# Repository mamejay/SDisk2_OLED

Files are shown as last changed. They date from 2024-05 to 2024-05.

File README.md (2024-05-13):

***** Updated Version Using SMD Components *****

I have updated the PCB to use all SMD components and tactile switches
I have re-compiled the code and confirmed is working.

# SDisk2 - Simplified

Disk II flopy drive emulator for Apple 2 computers

Objective. an Open Source Disk II floppy Disk emulator that is easy to make.  
See readme in firmware and PCB section for related info.

## Changes

* 27Mhz Xtal.
* OLED only. All LCD and Nokia LCD codes have been removed.
* All Screen rotation code removed.
* Buttons re-arranged

## To-do

1. Better documentaion of the code.

This project will be migrated to an ESP32 based SDISKII.
<https://github.com/terenceang/sdisk2esp>

## Authors

* (c) 2010 Koichi NISHIDA <tulip-house@msf.biglobe.ne.jp>
* (c) 2012 Victor Trucco
* (c) 2012 Fábio Belavenuto
* (c) 2015 Alexandre Suaide
* (c) 2022 Terence Ang

## License

This work is released under the version 3 of the GNU General Public License.

'''NOTE:'''
The current legal status of this code is uncertain.

Fábio and Alexandre have published files with a header that references the version 3 of the GNU General Public License, but it is not clear yet what's the licensing chosen by the original author, Koichi Nishida.

This repository will be updated once the actual licensing info is clarified by the authors.

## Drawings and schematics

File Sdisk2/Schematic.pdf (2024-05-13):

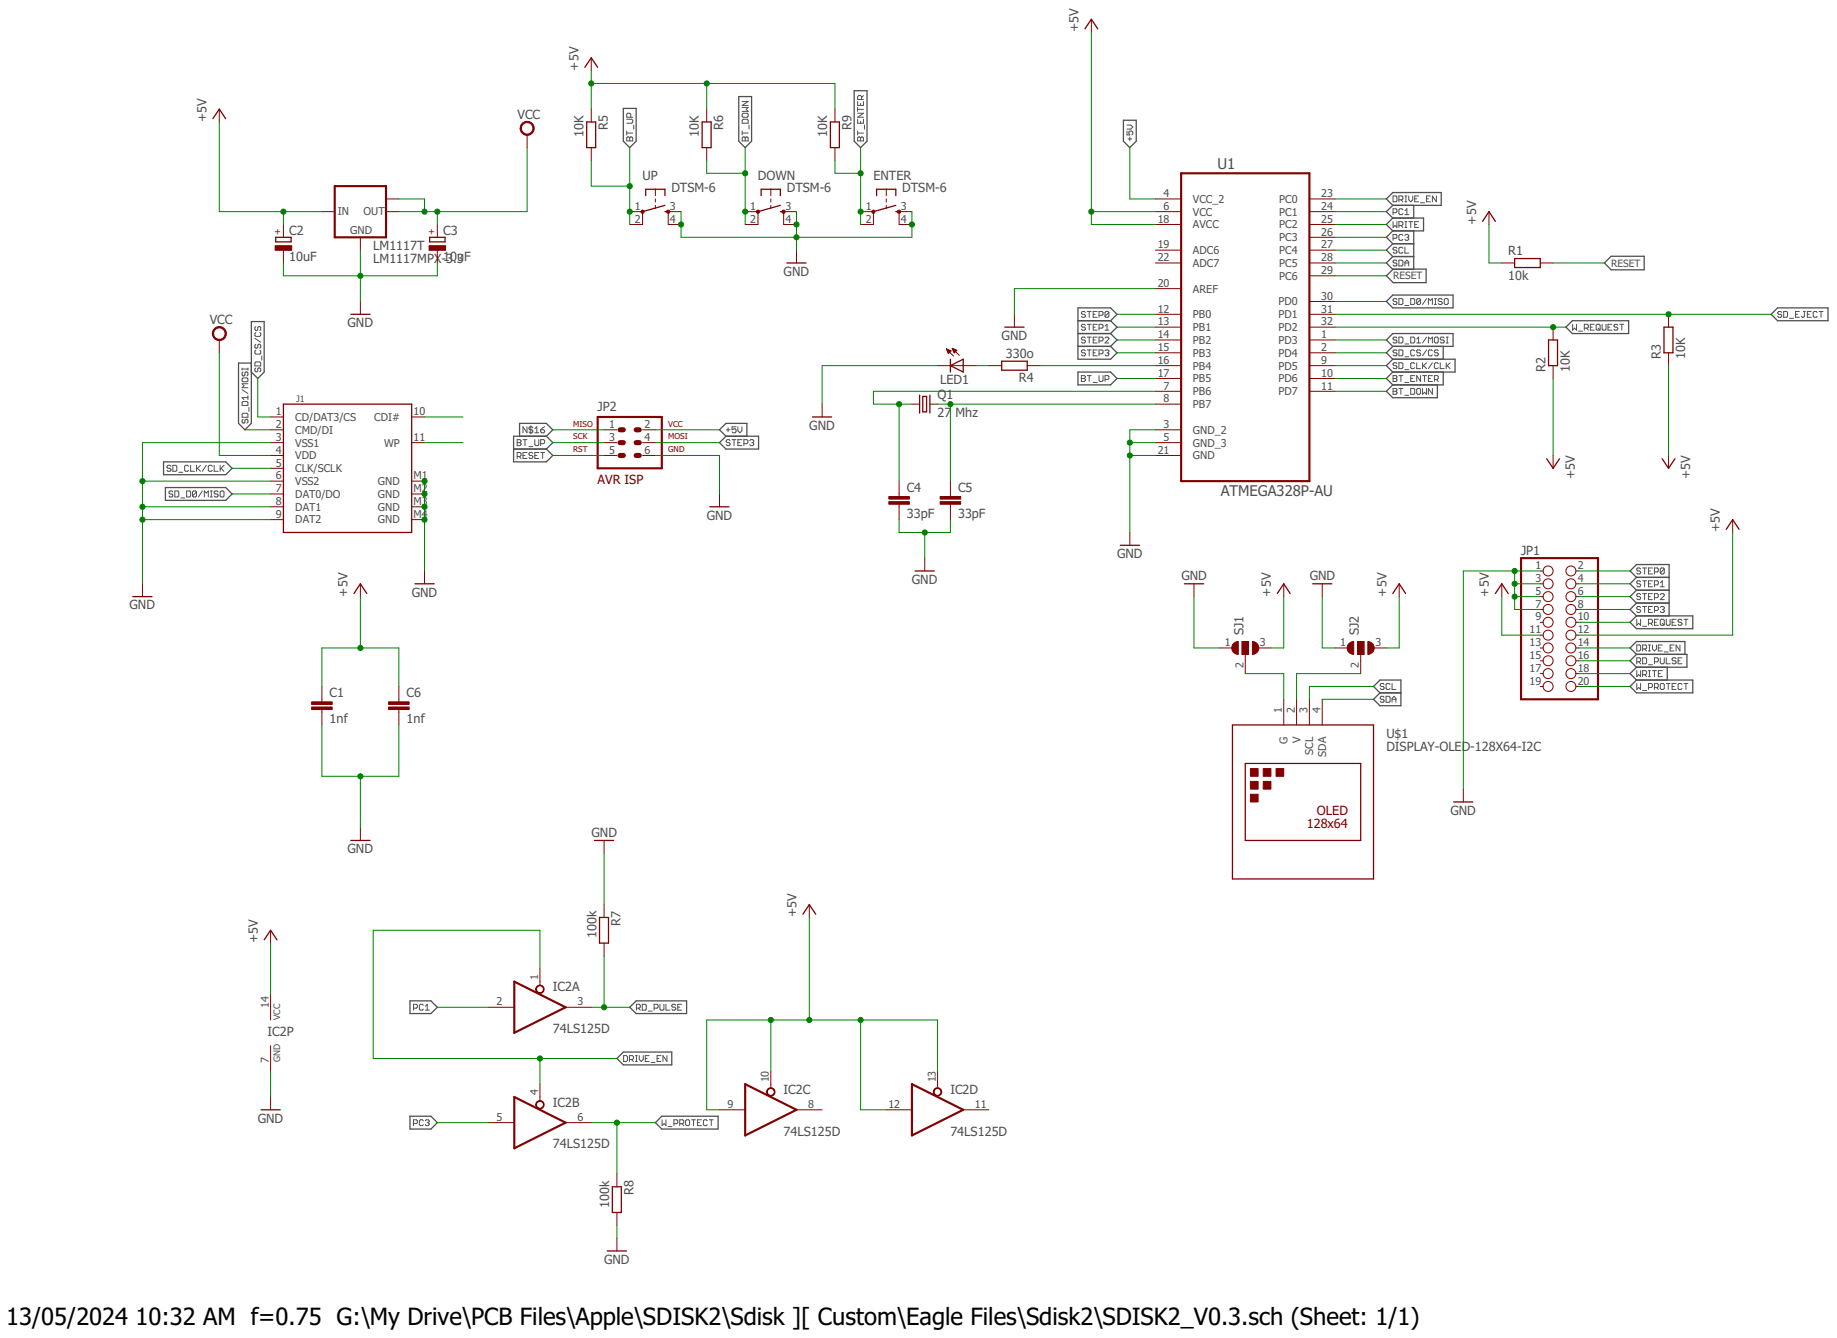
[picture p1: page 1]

13/05/2024 10:32 AM f=0.75 G:\My Drive\PCB Files\Apple\SDISK2\Sdisk ][ Custom\Eagle Files\Sdisk2\SDISK2_V0.3.sch (Sheet: 1/1)

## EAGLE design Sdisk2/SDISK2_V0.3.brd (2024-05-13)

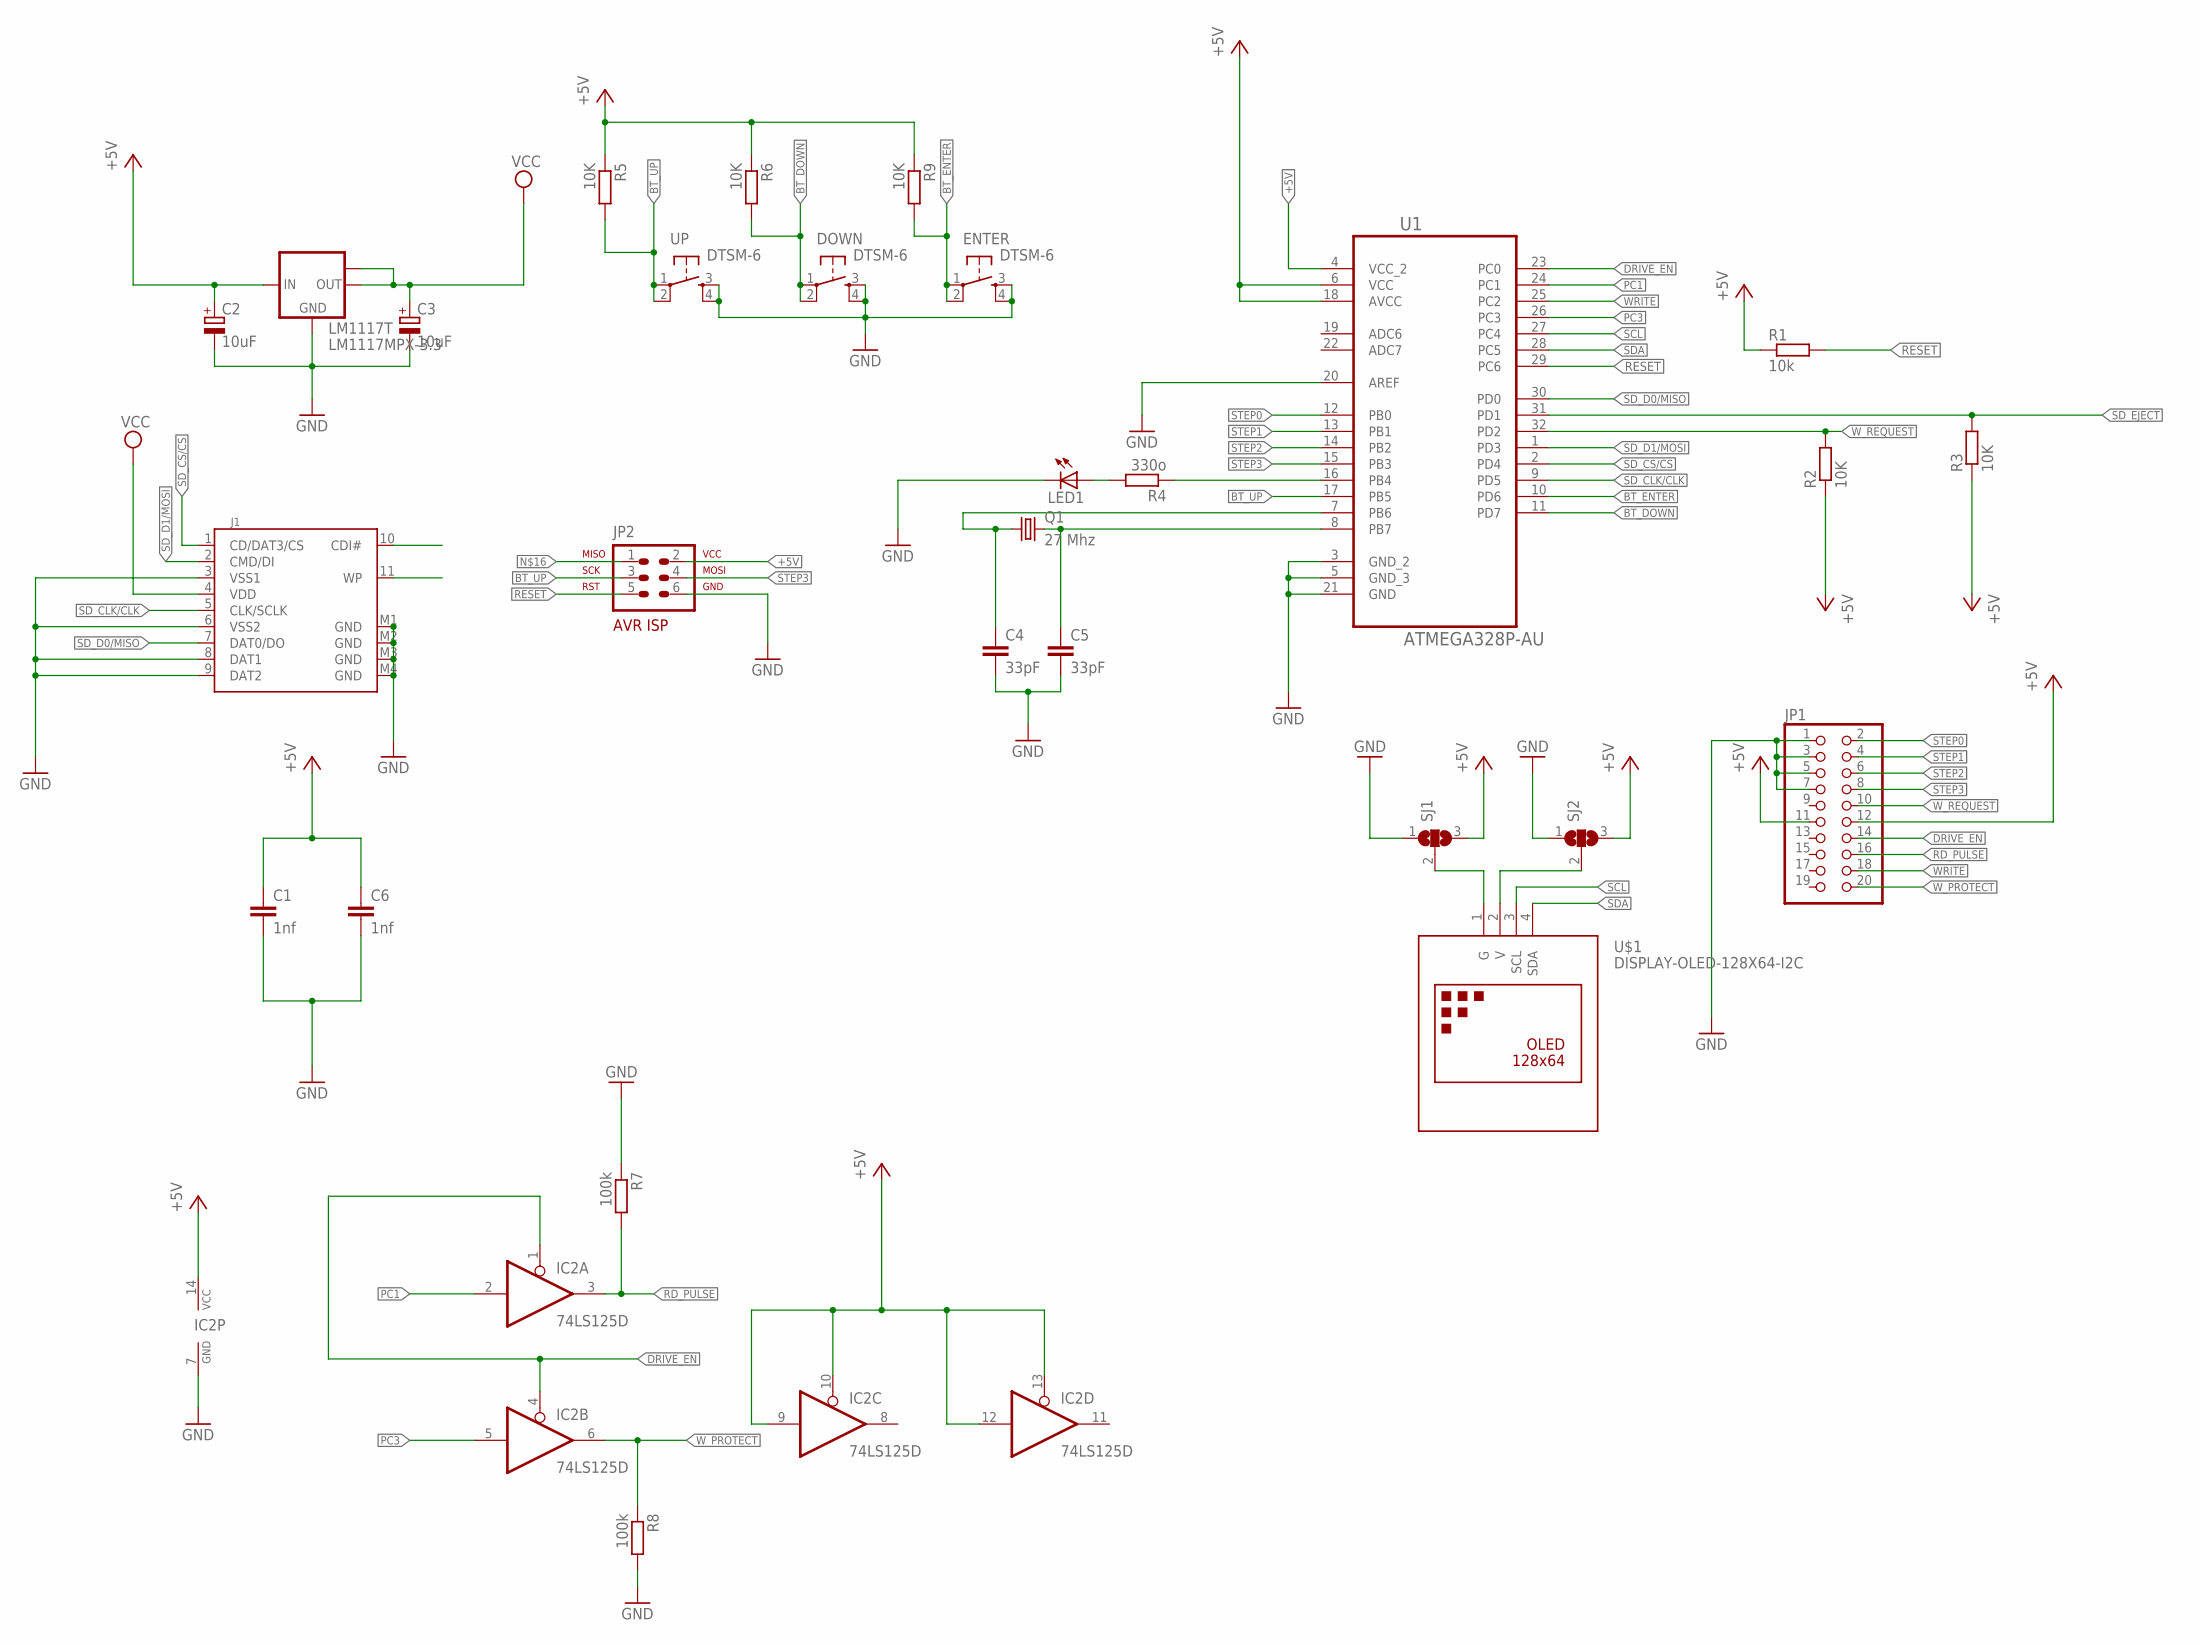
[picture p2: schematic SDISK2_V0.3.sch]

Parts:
C1, C6: 1nf; C0805
C2, C3: 10uF; 153CLV-0405
C4, C5: 33pF; C0805
DOWN: DTSM-6
ENTER: DTSM-6
IC2: 74LS125D; SO14
J1: SDCARD; SDCMF-10915W010
JP1: PINHD-2X10_IDC2X10_IDC_NEW; 2X10_IDC
JP2: AVR-ISP-6VERT; AVR-ISP-6
LED1: LEDSML1206; SML1206
LM1117T: LM1117MPX-3.3; SOT223
Q1: 27 Mhz; HC49UP
R1: 10k; R0805
R2, R3, R5, R6, R9: 10K; R0805
R4: 330o; R0805
R7, R8: 100k; R0805
SJ1, SJ2: SJ2W; SJ_2
U1: ATMEGA328P-AU; QFP80P900X900X120-32N
U$1: DISPLAY-OLED-128X64-I2C
UP: DTSM-6

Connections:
3.3V: C3.+, J1.4 (VDD), LM1117T.2 (OUT), LM1117T.TAB (OUT1)
+5V: C1.1, C2.+, C6.1, IC2.9 (I), IC2.10 (OE), IC2.12 (I), IC2.13 (OE), IC2.14 (VCC), JP1.11, JP1.12, JP2.2, LM1117T.3 (IN), R1.1, R2.1, R3.1, R5.1, R6.1, R9.1, SJ1.3, SJ2.3, U1.4 (VCC_2), U1.6 (VCC), U1.18 (AVCC)
BT_DOWN: DOWN.1, DOWN.2, R6.2, U1.11 (PD7)
BT_ENTER: ENTER.1, ENTER.2, R9.2, U1.10 (PD6)
BT_UP: JP2.3, R5.2, U1.17 (PB5), UP.1, UP.2
DRIVE_EN: IC2.1 (OE), IC2.4 (OE), JP1.14, U1.23 (PC0)
GND: C1.2, C2.-, C3.-, C4.2, C5.2, C6.2, DOWN.3, DOWN.4, ENTER.3, ENTER.4, IC2.7 (GND), J1.3 (VSS1), J1.6 (VSS2), J1.8 (DAT1), J1.9 (DAT2), J1.M1 (GND), J1.M2 (GND), J1.M3 (GND), J1.M4 (GND), JP1.1, JP1.3, JP1.5, JP1.7, JP2.6, LED1.C, LM1117T.1 (GND), R7.1, R8.2, SJ1.1, SJ2.1, U1.3 (GND_2), U1.5 (GND_3), U1.20 (AREF), U1.21 (GND), UP.3, UP.4
unnamed: C4.1, Q1.1, U1.7 (PB6)
unnamed: LED1.A, R4.2
unnamed: SJ1.2, U$1.1 (G)
unnamed: SJ2.2, U$1.2 (V)
unnamed: JP2.1, R4.1, U1.16 (PB4)
unnamed: C5.1, Q1.2, U1.8 (PB7)
PC1: IC2.2 (I), U1.24 (PC1)
PC3: IC2.5 (I), U1.26 (PC3)
RD_PULSE: IC2.3 (O), JP1.16, R7.2
RESET: JP2.5, R1.2, U1.29 (PC6)
SCL: U1.27 (PC4), U$1.3 (SCL)
SDA: U1.28 (PC5), U$1.4 (SDA)
SD_CLK/CLK: J1.5 (CLK/SCLK), U1.9 (PD5)
SD_CS/CS: J1.1 (CD/DAT3/CS), U1.2 (PD4)
SD_D0/MISO: J1.7 (DAT0/DO), U1.30 (PD0)
SD_D1/MOSI: J1.2 (CMD/DI), U1.1 (PD3)
SD_EJECT: R3.2, U1.31 (PD1)
STEP0: JP1.2, U1.12 (PB0)
STEP1: JP1.4, U1.13 (PB1)
STEP2: JP1.6, U1.14 (PB2)
STEP3: JP1.8, JP2.4, U1.15 (PB3)
WRITE: JP1.18, U1.25 (PC2)
W_PROTECT: IC2.6 (O), JP1.20, R8.1
W_REQUEST: JP1.10, R2.2, U1.32 (PD2)

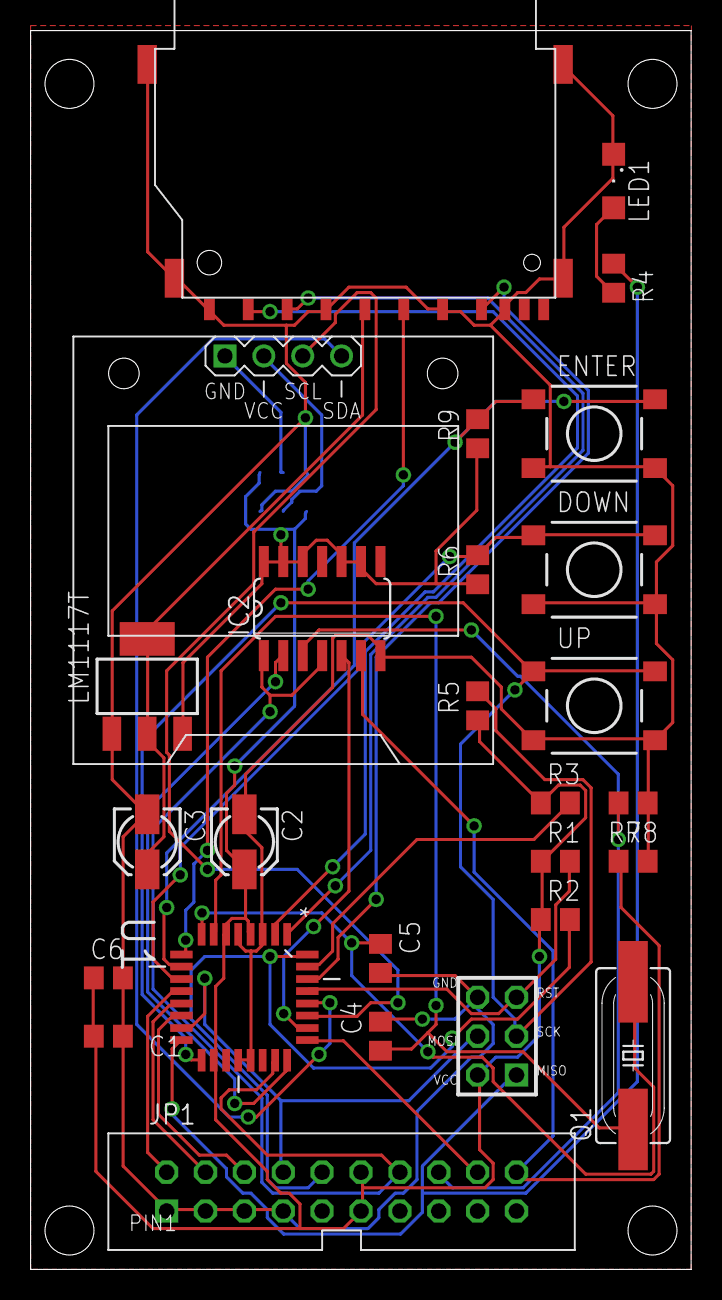
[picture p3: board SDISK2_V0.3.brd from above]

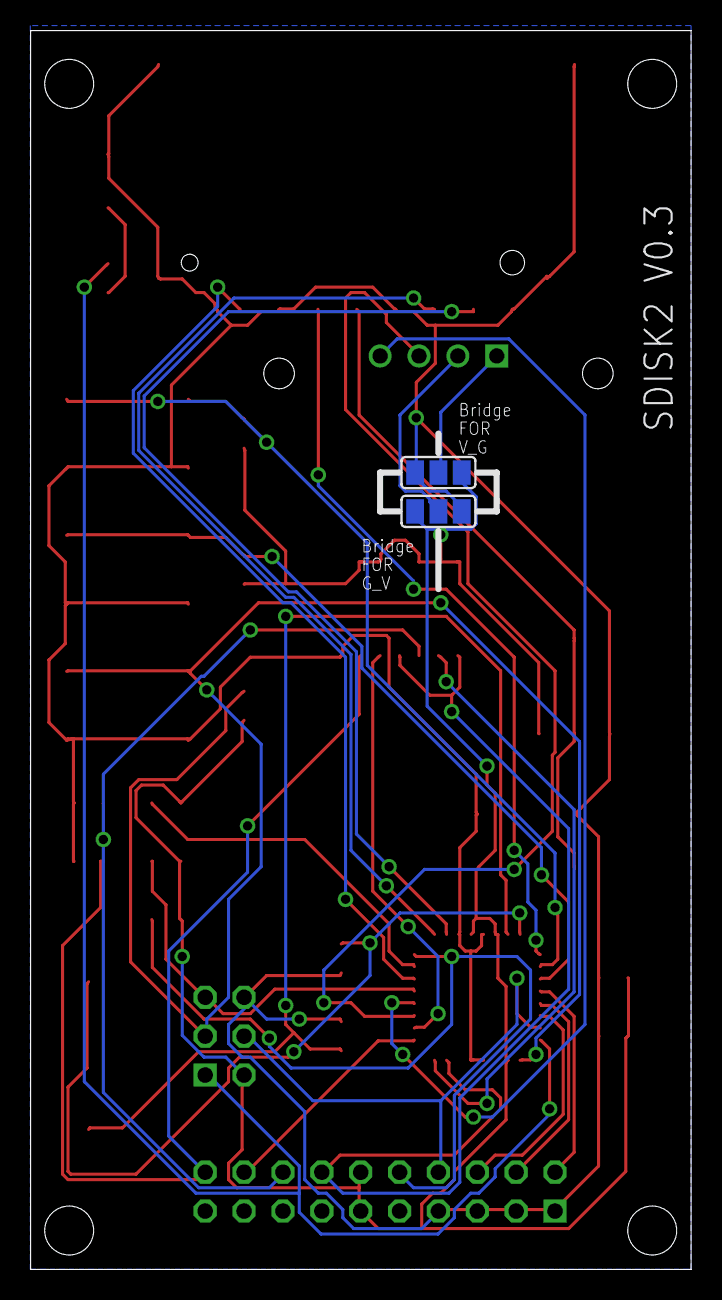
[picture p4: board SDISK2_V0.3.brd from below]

Board: 2 copper layers, 43.2 x 81.0 mm, 29 parts (2 on the bottom side), 31 nets.

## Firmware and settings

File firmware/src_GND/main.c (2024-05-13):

/*------------------------------------
SDISK II LCD Firmware
2010.11.11 by Koichi Nishida
2012.01.26 by Fábio Belavenuto
2015.07.02 by Alexandre Suaide
-------------------------------------
*/

/*
2015.07.02 by Alexandre Suaide
Added support for SDHC cards and subdirectories
Removed DSK to NIC conversion
FAT16 and FAT32 disks should have at least 64 blocks per cluster
*/

/*
2012.01.26 by Fábio Belavenuto
Added support for image exchange using a button added in the Brazilian version by Victor Trucco
Added support for a 16x2 LCD
*/

/*
This is a part of the firmware for DISK II emulator by Nishida Radio.
Copyright (C) 2010 Koichi NISHIDA
email to Koichi NISHIDA: tulip-house@msf.biglobe.ne.jp
This program is free software; you can redistribute it and/or modify it
under the terms of the GNU General Public License as published by
the Free Software Foundation; either version 3 of the License.
This program is distributed in the hope that it will be useful,
but WITHOUT ANY WARRANTY; without even the implied warranty of
MERCHANTABILITY or FITNESS FOR A PARTICULAR PURPOSE.
See the GNU General Public License for more details.
You should have received a copy of the GNU General Public License
along with this program. If not, see <http://www.gnu.org/licenses/>.
*/

#include "main.h"

#define BUF_NUM 4 // originalmente era 5. testando por conta de um possivel overflow de memoria na sdisk nova com oled
unsigned char writeData[BUF_NUM][350];
unsigned char sectors[BUF_NUM], tracks[BUF_NUM];
unsigned char buffNum;
unsigned char *writePtr;
unsigned char flip_buttons;

#define DEBOUNCE 200

#define MAXFILES 200
unsigned char *files_id;
int nfiles = 0;
int selected_file_id = 0;
int id_of_config_file = -1;

#define FAT_NIC_ELEMS 10
#define NIC_FILE_SIZE 280
unsigned long fatNic[FAT_NIC_ELEMS];

// DISK II status
unsigned char ph_track; // 0 - 139
unsigned char sector;	// 0 - 15
unsigned short bitbyte; // 0 - (8*512-1)
unsigned char prepare;
unsigned char readPulse;
unsigned char inited;
unsigned char magState;
unsigned char protect;
unsigned char formatting;
const unsigned char volume = 0xfe;

unsigned char trk;
unsigned short long_sector;
unsigned short long_cluster;
unsigned long ft;
unsigned char old_trk;

/*Error codes
1 - Can not put SD Card on idle state
2 - Can not make SD Card initialization
3 - Can not init FAT
4 - Partition type not supported (only FAT16 and FAT32)
5 - Cluster size smaller than minimum to keep buffer
*/

/*                               012345678901234567890*/
PROGMEM const char SPLASH1[] = "      SDISK ][";
PROGMEM const char VERSION[] = "  version " VER " " YEAR;
PROGMEM const char NIC[] = " NIC                 ";
PROGMEM const char SETUP[] = " SETUP               ";
PROGMEM const char EMP[] = "                     ";
PROGMEM const char SET1[] = " Set SD delay        ";
PROGMEM const char SET2[] = " Set contrast        ";
PROGMEM const char SET3[] = " Rotate display      ";
PROGMEM const char VALUE[] = " Value: ";
PROGMEM const char CONT[] = " LCD CONTRAST        ";
PROGMEM const char DLAY[] = " SD SELECT DELAY     ";
PROGMEM const char TRAK[] = "Track: ";
PROGMEM const char MSG7[] = " SELECT NIC          ";
PROGMEM const char MSGC[] = " Building list";
PROGMEM const char MSG8[] = " Nothing found here! ";
PROGMEM const char MSGD[] = " Sorting files ...   ";
PROGMEM const char MSHC[] = "SDHC card     ";
PROGMEM const char MSSD[] = "Normal SD card";
PROGMEM const char ERR[] = "E R R O R";
PROGMEM const char ERM1[] = "SD can't idle ";
PROGMEM const char ERM2[] = "SD can't init ";
PROGMEM const char ERM3[] = "Boot sector   ";
PROGMEM const char ERM4[] = "Not FAT16/32  ";
PROGMEM const char ERM5[] = "Cluster < 32kB";
PROGMEM const char ERM6[] = "Missing MBR   ";
PROGMEM const char ERM7[] = "SD Block ERROR";
PROGMEM const char ERMC[] = "Code: ";
PROGMEM const char PART[] = "Type: ";
PROGMEM const char FAT3[] = "FAT32";
PROGMEM const char FAT1[] = "FAT16";
PROGMEM const char SDOUT[] = "No SD inserted";
#define TRX 12
#define TRY 4

PROGMEM const char CFG[] = "SDISKII CFG";

// a table for head stepper motor movement
PROGMEM const prog_uchar stepper_table[4] = {0x0f, 0xed, 0x03, 0x21};

int main(void)
{
	static unsigned char oldStp = 0, stp;
	init(1);
	old_trk = 255;
	while (1)
	{
		verify_status();
		if (diskII_disable())
		{
			SD_led_off();
		}
		else
		{
			SD_led_on();
			stp = (PINB & 0b00001111);
			if (stp != oldStp)
			{
				oldStp = stp;
				unsigned char ofs = ((stp == 0b00001000) ? 2 : ((stp == 0b00000100) ? 4 : ((stp == 0b00000010) ? 6 : ((stp == 0b00000001) ? 0 : 0xff))));
				if (ofs != 0xff)
				{
					ofs = ((ofs + ph_track) & 7);
					unsigned char bt = pgm_read_byte_near(stepper_table + (ofs >> 1));
					oldStp = stp;
					if (ofs & 1)
						bt &= 0x0f;
					else
						bt >>= 4;
					ph_track += ((bt & 0x08) ? (0xf8 | bt) : bt);
					if (ph_track > 196)
						ph_track = 0;
					if (ph_track > 139)
						ph_track = 139;
				}
			}

			if (inited && prepare)
			{
				cli();
				sector = ((sector + 1) & 0xf);
				{
					trk = (ph_track >> 2);
					long_sector = (unsigned short)trk * 16 + sector;
					long_cluster = long_sector >> FAT_sectorsPerClusterBitShift;
					ft = fatNic[long_cluster];
					if (trk != old_trk)
					{
						old_trk = trk;
						ssd1306_gotoxy(TRX, TRY);
						ssd1306_put_p(TRAK);
						if (trk < 10)
							ssd1306_string(" ");
						ssd1306_put_i((unsigned int)trk);
					}

					if (((sectors[0] == sector) && (tracks[0] == trk)) || ((sectors[1] == sector) && (tracks[1] == trk)) ||
						((sectors[2] == sector) && (tracks[2] == trk)) || ((sectors[3] == sector) && (tracks[3] == trk)))
						writeBackSub();

					// Timing is an issue here. This is the reason I copied explicitly the conversion from cluster to block
					// instead of using getCluster() method. I also did bit shift instead of multiplications to make it faster.
					// even inline function is not fast enough.
					// SD_CMD17Special is also faster than the regular SD_sendCommand method.
					SD_CMD17Special((((ft - 2) << FAT_sectorsPerClusterBitShift) + FAT_firstDataSector) + (long_sector & (FAT_sectorsPerCluster - 1)));
					bitbyte = 0;
					prepare = 0;
				}

				sei();
			}
		}
	}
}

void display_sd_ejected()
{

	ssd1306_clear();
	ssd1306_gotoxy(37, 2);
	ssd1306_put_p(ERR);
	ssd1306_gotoxy(22, 4);
	ssd1306_put_p(SDOUT);

	do
	{
	} while (SD_ejected());
	return;
}

char init_sd(char splash)
{
	id_of_config_file = -1;
	SPI_slow();
	SD_select_card();
	unsigned char ok;
	if (SD_ejected())
	{
		display_sd_ejected();
		return 0;
	}

	buffer = &writeData[0][0];
	ok = SD_init();

	if (!ok)
	{
		ssd1306_clear();
		ssd1306_gotoxy(37, 2);
		ssd1306_put_p(ERR);
		ssd1306_gotoxy(22, 4);
		if (errorCode == 1)
			ssd1306_put_p(ERM1);
		else if (errorCode == 2)
			ssd1306_put_p(ERM2);
		else if (errorCode == 3)
			ssd1306_put_p(ERM3);
		else if (errorCode == 4)
			ssd1306_put_p(ERM4);
		else if (errorCode == 5)
			ssd1306_put_p(ERM5);
		else if (errorCode == 6)
			ssd1306_put_p(ERM6);
		else if (errorCode == 7)
			ssd1306_put_p(ERM7);
		else
		{
			ssd1306_put_p(ERMC);
			ssd1306_put_i(errorCode);
		}
		inited = 0;
		while (!SD_ejected())
		{
		};
		return 0;
	}

	if (splash)
	{
		ssd1306_clear();
		ssd1306_gotoxy(0, 2);

		if (SD_version == SD_RAW_SPEC_SDHC)
			ssd1306_put_p(MSHC);
		else
			ssd1306_put_p(MSSD);

		SD_select_card();
		_delay_ms(1000);
	}

	ok = FAT_init();
	if (!ok)
	{
		ssd1306_clear();
		ssd1306_gotoxy(37, 2);
		ssd1306_put_p(ERR);
		ssd1306_gotoxy(22, 4);

		if (errorCode == 1)
			ssd1306_put_p(ERM1);
		else if (errorCode == 2)
			ssd1306_put_p(ERM2);
		else if (errorCode == 3)
			ssd1306_put_p(ERM3);
		else if (errorCode == 4)
			ssd1306_put_p(ERM4);
		else if (errorCode == 5)
			ssd1306_put_p(ERM5);
		else if (errorCode == 6)
			ssd1306_put_p(ERM6);
		else if (errorCode == 7)
			ssd1306_put_p(ERM7);
		else
		{
			ssd1306_put_p(ERMC);
			ssd1306_put_i(errorCode);
		}
		inited = 0;
		while (!SD_ejected())
		{
		};
		return 0;
	}

	if ((FAT_bytesPerSector * FAT_sectorsPerCluster / 1024) < (NIC_FILE_SIZE / FAT_NIC_ELEMS))
	{
		errorCode = 5;
		ssd1306_clear();
		ssd1306_gotoxy(37, 2);
		ssd1306_put_p(ERR);
		ssd1306_gotoxy(22, 4);
		ssd1306_put_p(ERM5);

		inited = 0;
		while (!SD_ejected())
		{
		};
		return 0;
	}

	if (splash)
	{
		ssd1306_gotoxy(0, 4);

		ssd1306_put_p(PART);
		if (FAT_partitionType == PARTITION_TYPE_FAT16)
			ssd1306_put_p(FAT1);
		else
			ssd1306_put_p(FAT3);

		_delay_ms(1000);
		// SD_select_card();
	}
	SD_select_card();
	buffClear();
	SPI_fast();
	return 1;
}

void init(char splash)
{
	// configuracao das portas do microcontrolador

	DDRB = 0;
	DDRC = 0;
	DDRD = 0;

	PORTB = 0;
	PORTC = 0;
	PORTD = 0;

	// configuração do LED
	set_bit(SD_LED_PORTD, SD_LED);
	set_bit(SD_LED_PORT, SD_LED); // LED ligado

	// configuração da interface com o Apple
	set_bit(DDRC, 1);
	set_bit(DDRC, 3);
	set_bit(PORTC, 1);

	// configuração da interrupção de tempo
	OCR0A = 0;
	TCCR0A = 0;
	TCCR0B = 1;

	// configuração da interrupção int0
	MCUCR = 0b00000010;
	EICRA = 0b00000010;

	sector = 0;
	inited = 0;
	readPulse = 0;
	protect = 0;
	bitbyte = 0;
	magState = 0;
	prepare = 1;
	ph_track = 0;
	buffNum = 0;
	formatting = 0;
	writePtr = &(writeData[buffNum][0]);

	if (splash)
	{
		ssd1306_init();
		ssd1306_clear();
		ssd1306_gotoxy(0, 0);
		logo();
		ssd1306_gotoxy(13, 6);
		ssd1306_put_p(SPLASH1);
		ssd1306_gotoxy(7, 7);
		ssd1306_put_p(VERSION);
		_delay_ms(1500);
	}
}

void verify_status(void)
{
	unsigned int i;
	configButtons();
	if (SD_ejected())
	{
		for (i = 0; i != 0xFF; i++)
			if (!SD_ejected())
				return;
		TIMSK0 &= ~(1 << TOIE0);
		EIMSK &= ~(1 << INT0);
		inited = 0;
		prepare = 0;
		display_sd_ejected();
		return;
	}
	else if (diskII_disable() && (enter_is_pressed() || down_is_pressed() || up_is_pressed()))
	{
		if (enter_is_pressed()) // drive disabled
		{
			unsigned char flg = 1;
			for (i = 0; i != 100; i++)
				if (!enter_is_pressed())
					flg = 0;
			if (flg)
			{
				while (enter_is_pressed())
					; // enter button pushed !
				cli();
				select_nic();
				if (SD_ejected())
					return;
				if (inited)
				{
					TIMSK0 |= (1 << TOIE0);
					EIMSK |= (1 << INT0);
				}
				sei();
			}
			return;
		}

		else if (down_is_pressed()) // setup
		{
			unsigned char flg = 1;
			for (i = 0; i != 100; i++)
				if (!down_is_pressed())
					flg = 0;
			if (flg)
			{
				while (down_is_pressed())
					; // enter button pushed !
				cli();
				setup();
				if (SD_ejected())
					return;
				find_previous_nic();
				if (inited)
				{
					TIMSK0 |= (1 << TOIE0);
					EIMSK |= (1 << INT0);
				}
				sei();
			}
			return;
		}
		else if (up_is_pressed())
		{
			unsigned char flg = 1;
			for (i = 0; i != 100; i++)
				if (!up_is_pressed())
					flg = 0;
			if (flg)
			{
				while (up_is_pressed())
					; // botao ainda apertado
				cli();
				swap_nic();
				if (SD_ejected())
					return;
				if (inited)
				{
					TIMSK0 |= (1 << TOIE0);
					EIMSK |= (1 << INT0);
				}
				sei();
			}
		}
	}
	else if (!inited) // if not initialized
	{
		for (i = 0; i != 0xFF; i++)
			if (SD_ejected())
				return;
		cli();
		if (init_sd(1))
			find_previous_nic();
		if (inited)
		{

			TIMSK0 |= (1 << TOIE0);
			EIMSK |= (1 << INT0);
		}
		sei();
	}
}

// Contrast Page
void set_contrast()
{
	unsigned char contrast = 0XAF;
	if (id_of_config_file != -1)
	{
		cd(0);
		buffer = &writeData[0][0];
		buffClear();
		lastBlockRead = 0;
		struct dir_Structure *config_file = getFile(id_of_config_file);
		unsigned long cluster;

		if (FAT_partitionType == PARTITION_TYPE_FAT32)
			cluster = (unsigned long)config_file->firstClusterHI << 16 | (unsigned long)config_file->firstClusterLO;
		else
			cluster = (unsigned long)config_file->firstClusterLO;

		SD_readSingleBlock(getSector(cluster));
		struct Sdisk_config_structure *config = (struct Sdisk_config_structure *)buffer;
		if (config->checksum == CHECKSUM_CONFIG)
		{
			contrast = config->oled_contrast;
		}
	}
	ssd1306_clear();
	ssd1306_gotoxy(0, 0);
	ssd1306_underline();
	ssd1306_put_p(CONT);
	ssd1306_underline();
	icons(3, 4, 5); // 5-enter, 4-down, 3-up

	ssd1306_gotoxy(0, 2);
	ssd1306_put_p(VALUE);
	ssd1306_put_i(contrast);

	unsigned char old_contrast = contrast;
	unsigned char original_contrast = contrast;
	while (1)
	{
		configButtons();
		if (contrast != old_contrast)
		{
			ssd1306_gotoxy(0, 2);
			ssd1306_put_p(VALUE);
			ssd1306_put_i(contrast);
			ssd1306_put_p(PSTR(" "));
			old_contrast = contrast;
		}

		if (SD_ejected())
			return; // card is removed
		if (down_is_pressed())
		{
			while (down_is_pressed())
			{
			}
			_delay_ms(DEBOUNCE);

			contrast--;
			if (contrast < MIN_CONTRAST)
				contrast = MIN_CONTRAST;
			else
			{
				oled_contrast = contrast;
				ssd1306_contrast(oled_contrast);
			}
		}
		if (up_is_pressed())
		{
			while (up_is_pressed())
			{
			}
			_delay_ms(DEBOUNCE);

			contrast++;
			if (contrast > MAX_CONTRAST)
				contrast = MAX_CONTRAST;
			else
			{
				oled_contrast = contrast;
				ssd1306_contrast(oled_contrast);
			}
		}
		if (enter_is_pressed())
		{
			while (enter_is_pressed())
			{
			}
			_delay_ms(DEBOUNCE);
			if (contrast != original_contrast)
			{
				oled_contrast = contrast;
				ssd1306_contrast(oled_contrast);
				SD_select_card();
				if (id_of_config_file != -1)
				{
					cd(0);
					buffer = &writeData[0][0];
					buffClear();
					lastBlockRead = 0;
					struct dir_Structure *config_file = getFile(id_of_config_file);
					unsigned long cluster;

					if (FAT_partitionType == PARTITION_TYPE_FAT32)
						cluster = (unsigned long)config_file->firstClusterHI << 16 | (unsigned long)config_file->firstClusterLO;
					else
						cluster = (unsigned long)config_file->firstClusterLO;

					SD_readSingleBlock(getSector(cluster));
					struct Sdisk_config_structure *config = (struct Sdisk_config_structure *)buffer;
					if (config->checksum == CHECKSUM_CONFIG)
					{
						config->oled_contrast = contrast;
						SD_writeSingleBlock(getSector(cluster));
					}
				}
			}
			return;
		}
	}
	return;
}

// Setup Page
void setup()
{
	ssd1306_clear();
	ssd1306_gotoxy(0, 0);
	ssd1306_underline();
	ssd1306_put_p(SETUP);
	ssd1306_underline();

	icons(3, 4, 5); // 5-enter, 4-down, 3-up

	unsigned char option = 1;
	ssd1306_gotoxy(0, 2);
	ssd1306_inverse();
	ssd1306_put_p(SET1); // set speed
	ssd1306_inverse();
	ssd1306_gotoxy(0, 3);
	ssd1306_put_p(SET2); // set contrast

#define MAX_SET 2 // number of item

	while (1)
	{
		configButtons();
		if (down_is_pressed())
		{
			while (down_is_pressed())
			{
			}
			_delay_ms(DEBOUNCE);

			option++;
			if (option > MAX_SET)
				option = MAX_SET;
			else
			{
				if (option == 1)
					ssd1306_inverse();
				ssd1306_gotoxy(0, 2);
				ssd1306_put_p(SET1);
				if (option == 1)
					ssd1306_inverse();

				if (option == 2)
					ssd1306_inverse();
				ssd1306_gotoxy(0, 3);
				ssd1306_put_p(SET2);
				if (option == 2)
					ssd1306_inverse();
			}
		}
		if (up_is_pressed())
		{
			while (up_is_pressed())
			{
			}
			_delay_ms(DEBOUNCE);

			option--;
			if (option < 1)
				option = 1;
			else
			{
				if (option == 1)
					ssd1306_inverse();
				ssd1306_gotoxy(0, 2);
				ssd1306_put_p(SET1);
				if (option == 1)
					ssd1306_inverse();

				if (option == 2)
					ssd1306_inverse();
				ssd1306_gotoxy(0, 3);
				ssd1306_put_p(SET2);
				if (option == 2)
					ssd1306_inverse();
			}
		}
		if (enter_is_pressed())
		{
			while (enter_is_pressed())
			{
			}
			_delay_ms(DEBOUNCE);
			if (option == 1)
				set_speed();
			if (option == 2)
				set_contrast();
			return;
		}
	}
}

void icons(unsigned char i1, unsigned char i2, unsigned char i3)
{

#define IC_LINE 7
#define IC_1 0
#define IC_2 58
#define IC_3 115

	ssd1306_gotoxy(IC_1, IC_LINE);
	ssd1306_overline();
	ssd1306_put_p(EMP);
	ssd1306_gotoxy(IC_1, IC_LINE);
	ssd1306_icon(i1);
	ssd1306_gotoxy(IC_2, IC_LINE);
	ssd1306_icon(i2);
	ssd1306_gotoxy(IC_3, IC_LINE);
	ssd1306_icon(i3);
	ssd1306_overline();
}

void set_speed()
{
	ssd1306_clear();
	ssd1306_gotoxy(0, 0);
	ssd1306_underline();
	ssd1306_put_p(DLAY);
	ssd1306_underline();
	icons(3, 5, 4); // 5-setup, 4-Disk, 3-last Disk
	ssd1306_gotoxy(0, 3);
	ssd1306_put_p(VALUE);
	ssd1306_put_i(SD_speed);

	unsigned char old_speed = SD_speed;
	unsigned char original_speed = SD_speed;
	while (1)
	{
		configButtons();
		if (SD_speed != old_speed)
		{

			ssd1306_gotoxy(0, 3);
			ssd1306_put_p(VALUE);
			ssd1306_put_i(SD_speed);
			ssd1306_put_p(PSTR(" "));
			old_speed = SD_speed;
		}

		if (SD_ejected())
			return; // card is removed
		if (down_is_pressed())
		{
			while (down_is_pressed())
			{
			}
			_delay_ms(DEBOUNCE);

			SD_speed--;
			if (SD_speed < SD_MIN_SPEED)
				SD_speed = SD_MAX_SPEED;
		}
		if (up_is_pressed())
		{
			while (up_is_pressed())
			{
			}
			_delay_ms(DEBOUNCE);

			SD_speed++;
			if (SD_speed > SD_MAX_SPEED)
				SD_speed = SD_MIN_SPEED;
		}
		if (enter_is_pressed())
		{
			while (enter_is_pressed())
			{
			}
			_delay_ms(DEBOUNCE);
			if (SD_speed != original_speed)
			{
				if (id_of_config_file != -1)
				{
					cd(0);
					buffer = &writeData[0][0];
					buffClear();
					lastBlockRead = 0;
					struct dir_Structure *config_file = getFile(id_of_config_file);
					unsigned long cluster;

					if (FAT_partitionType == PARTITION_TYPE_FAT32)
						cluster = (unsigned long)config_file->firstClusterHI << 16 | (unsigned long)config_file->firstClusterLO;
					else
						cluster = (unsigned long)config_file->firstClusterLO;

					SD_readSingleBlock(getSector(cluster));
					struct Sdisk_config_structure *config = (struct Sdisk_config_structure *)buffer;
					if (config->checksum == CHECKSUM_CONFIG)
					{
						config->sd_card_speed = SD_speed;
						SD_writeSingleBlock(getSector(cluster));
					}
				}
			}
			return;
		}
	}
	return;
}

// Nic Selection Page
void select_nic()
{
	int i = 0, j = 0, k = 0;
	char name1[8];
	nfiles = 0;
	buffer = &writeData[0][0];
	files_id = &writeData[2][0];
	lastBlockRead = -1;
	buffClear();

	ssd1306_underline();
	ssd1306_gotoxy(0, 0);
	ssd1306_put_p(MSG7);
	ssd1306_underline();
	icons(3, 4, 5); // 3-up, 4-down, 5-enter
	for (i = 1; i <= 5; i++)
	{
		ssd1306_gotoxy(0, i);
		ssd1306_put_p(EMP);
	}
	ssd1306_gotoxy(0, 3);
	ssd1306_put_p(MSGC);

	i = 0;

	do
	{
		struct dir_Structure *file = getFile(i);
		if (file)
			if (file->name[0] == 0x00)
				break; // last file on directory
		if (is_a_nic(file) || is_a_dir(file))
		{
			files_id[nfiles] = i;
			nfiles++;
		}
		i++;
	} while (nfiles < MAXFILES && i < MAXFILES * 2);

	if (nfiles == 0)
	{
		ssd1306_gotoxy(0, 3);
		ssd1306_put_p(MSG8);
		return;
	}

	ssd1306_gotoxy(0, 3);
	ssd1306_put_p(MSGD);

	// sort list of files in the directory
	if (nfiles > 1)
	{
		for (i = 0; i <= (nfiles - 2); i++)
		{
			for (j = 1; j <= (nfiles - i - 1); j++)
			{
				struct dir_Structure *file1 = getFile(files_id[j]);
				strlcpy(name1, (const char *)file1->name, 8);
				struct dir_Structure *file2 = getFile(files_id[j - 1]);
				if (memcmp(name1, file2->name, 8) < 0)
				{
					k = files_id[j];
					files_id[j] = files_id[j - 1];
					files_id[j - 1] = k;
				}
			}
		}
	}

	int index = 0;
	for (i = 0; i < nfiles; i++)
		if (selected_file_id == files_id[i])
			index = i;
	int index_old = -1;
	while (1)
	{
		configButtons();
		if (SD_ejected())
			return; // card is removed
		if (down_is_pressed())
		{
			while (down_is_pressed())
			{
			}
			_delay_ms(DEBOUNCE);

			index++;
			if (index == nfiles)
				index = 0;
		}
		if (up_is_pressed())
		{
			while (up_is_pressed())
			{
			}
			_delay_ms(DEBOUNCE);

			index--;
			if (index < 0)
				index = nfiles - 1;
		}
		if (enter_is_pressed())
		{
			while (enter_is_pressed())
			{
			}
			_delay_ms(DEBOUNCE);
			struct dir_Structure *file = getFile(files_id[index]);
			if (is_a_dir(file))
			{
				cd(file);
				select_nic();
				return;
			}
			else
			{
				mount_nic_image(files_id[index], file);
				return;
			}
			return;
		}
		if (index != index_old)
		{
			index_old = index;
			struct dir_Structure *file = getFile(files_id[index]);

			ssd1306_gotoxy(0, 3);
			if (is_a_dir(file))
				ssd1306_icon(6);
			else
				ssd1306_icon(1);
			unsigned char count = 0;
			for (int i = 0; i < 8; i++)
				if (file->name[i] != ' ')
				{
					ssd1306_char(file->name[i]);
					count++;
				}
			for (int i = count; i < 16; i++)
				ssd1306_char(' ');
		}
	}
}
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

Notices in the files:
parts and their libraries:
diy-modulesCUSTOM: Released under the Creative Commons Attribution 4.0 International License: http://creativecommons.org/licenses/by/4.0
